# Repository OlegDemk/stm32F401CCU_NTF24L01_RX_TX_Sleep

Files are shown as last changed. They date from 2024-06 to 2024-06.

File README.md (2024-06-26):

The project base on STM32F401CCU microcontroller and NRF24L01 radio module. Project was create on STM32 Cube IDE. 
The RX project: TR all time listen TX modules(up to 6), mark from witch PIPE was(from what TX module data transmeeted), and transmeet reseived data into UART. 

The TX project: Transmeet this data: (32 bytes/one packet)
1. Temperature, Humidity from BME280.
2. Battery voltage. 
3. Retransmitted data packets counter and lost data packets counter. (need for detect lost packets).
After data transmeeting, TX devise go into Stenby mode.
The power consumption(STM32+NRF24l01+BME280) into this mode around 37uA, in condition when device woke up every 5 seconds, and transmeet data every 60 seconds.

Power Consumption
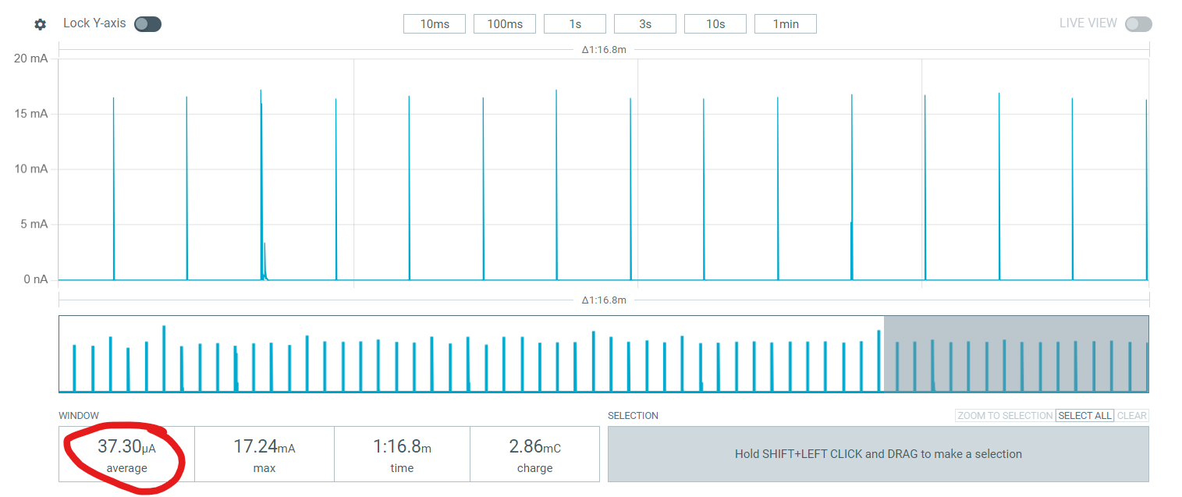
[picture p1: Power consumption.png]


Data:


Settings located on the main.h file
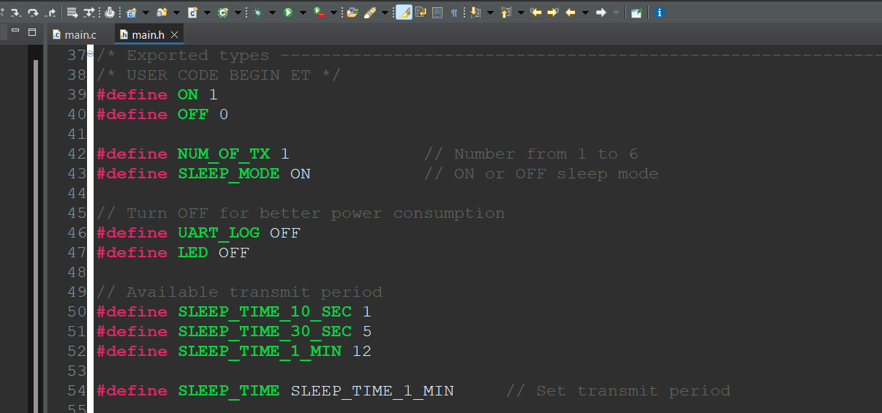
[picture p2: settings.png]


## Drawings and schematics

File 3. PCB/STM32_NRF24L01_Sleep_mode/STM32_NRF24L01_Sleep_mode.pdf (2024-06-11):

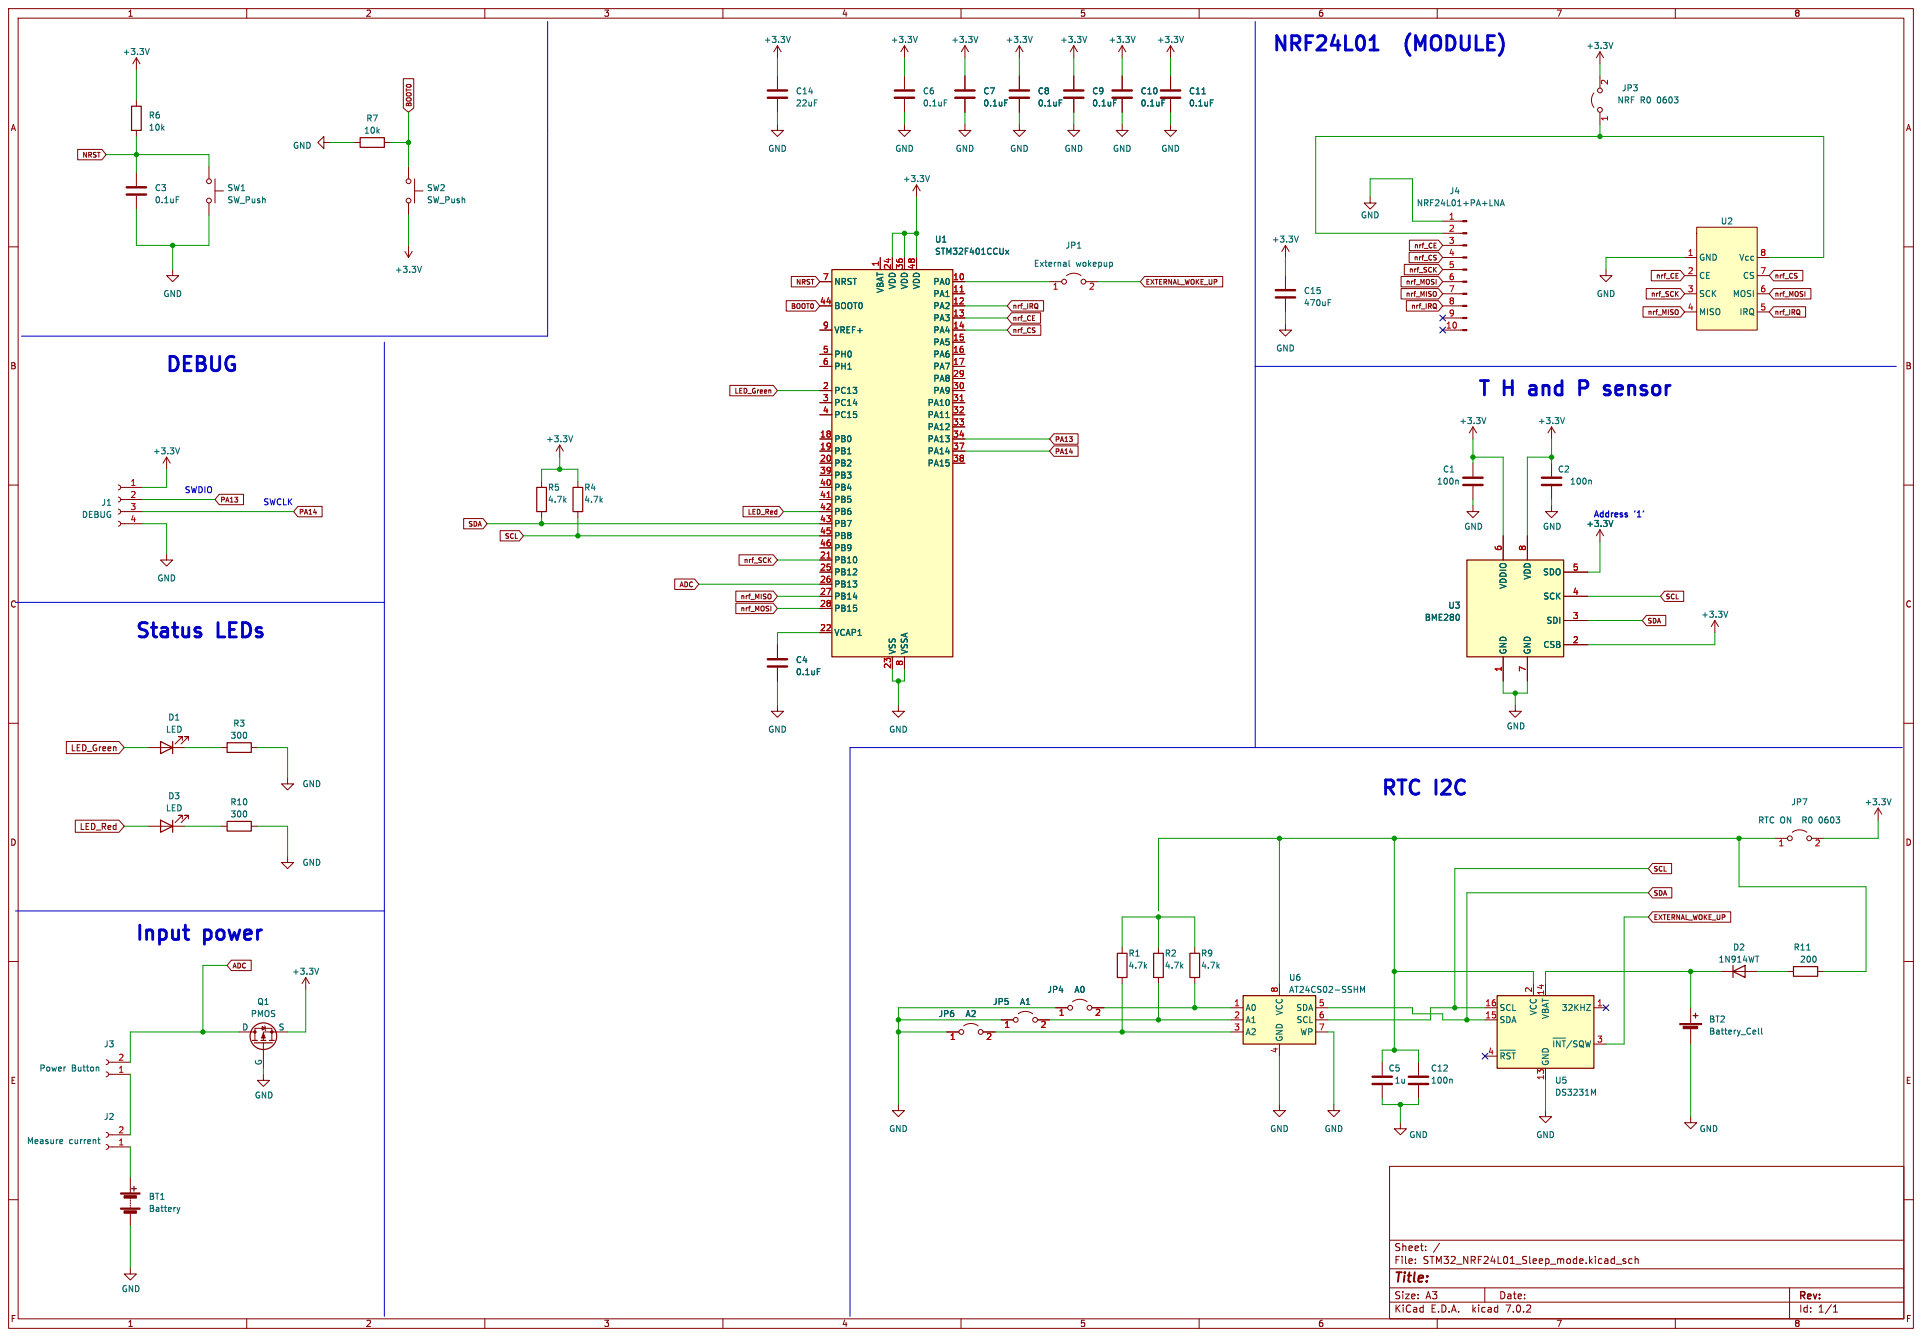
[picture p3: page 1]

nrf_IRQ https://arduino.ua/ru/prod3649-nrf24l01palna-wireless-transceiver-communication-module

1 PA0 10 PA1 11 PA2 12 PA3 13 PA4 14 PA5 15 PA6 16 PA7 17 PB0 18 PB1 19 PC13 2 PB2 20 PB10 21 VCAP1 22 VSS 23 VDD 24 PB12 25 PB13 26 PB14 27 PB15 28 PA8 29 PC14 3 PA9 30 PA10 31 PA11 32 PA12 33 PA13 34 VDD 36 PA14 37 PA15 38 PB3 39 PC15 4 PB4 40 PB5 41 PB6 42 PB7 43 BOOT0 44 PB8 45 PB9 46 VDD 48 PH0 5 PH1 6 NRST 7 VSSA

1 CSB 2 SDI 3 SCK 4 SDO 5 VDDIO

4 SDA 5 SCL 6 WP 7 VCC

Id: 1/1 Title: File: STM32_NRF24L01_Sleep_mode.kicad_sch Sheet: /

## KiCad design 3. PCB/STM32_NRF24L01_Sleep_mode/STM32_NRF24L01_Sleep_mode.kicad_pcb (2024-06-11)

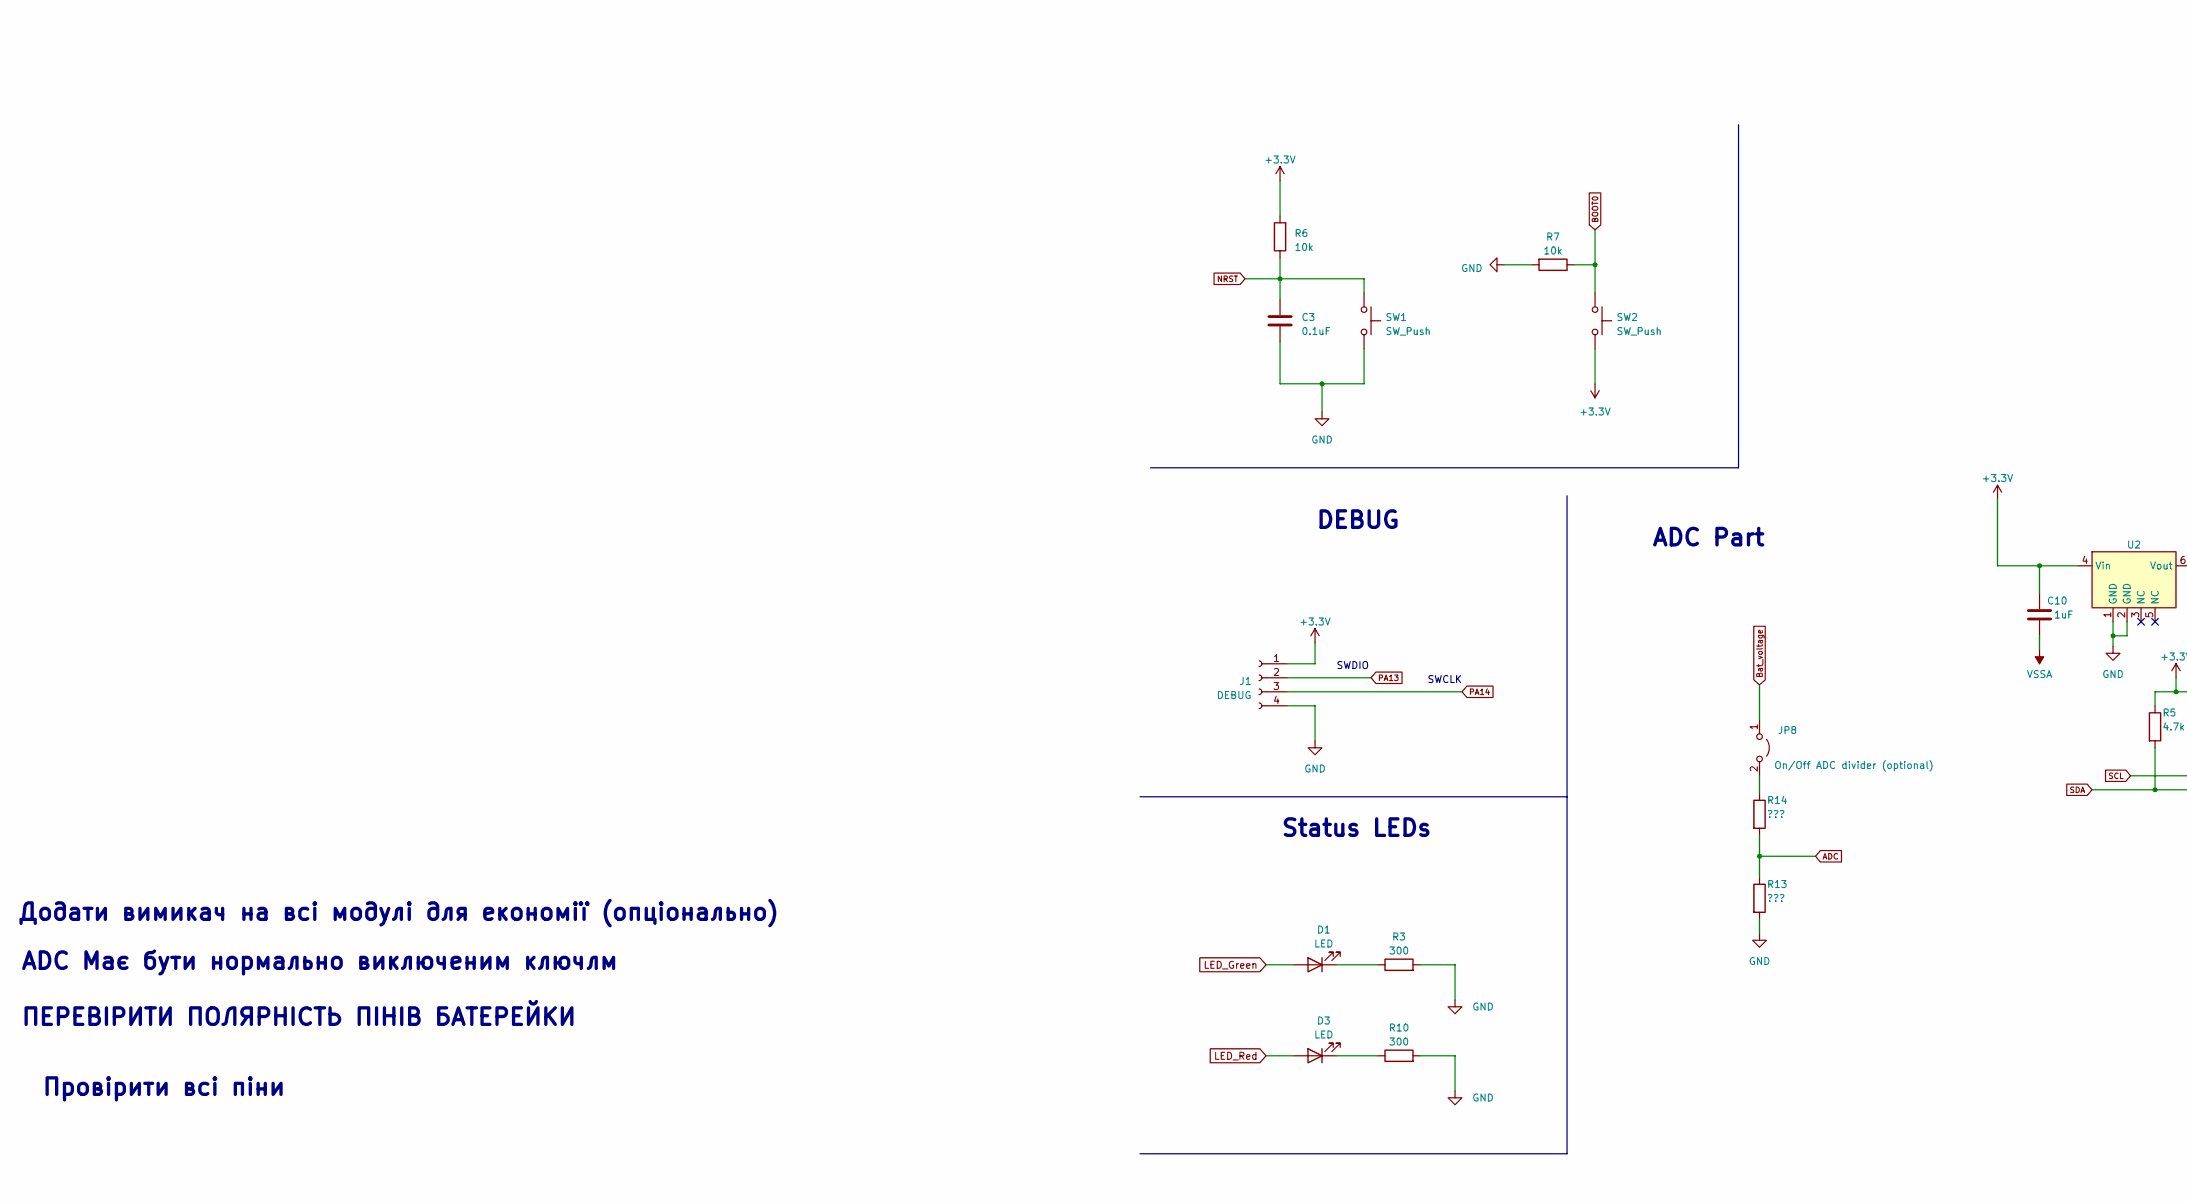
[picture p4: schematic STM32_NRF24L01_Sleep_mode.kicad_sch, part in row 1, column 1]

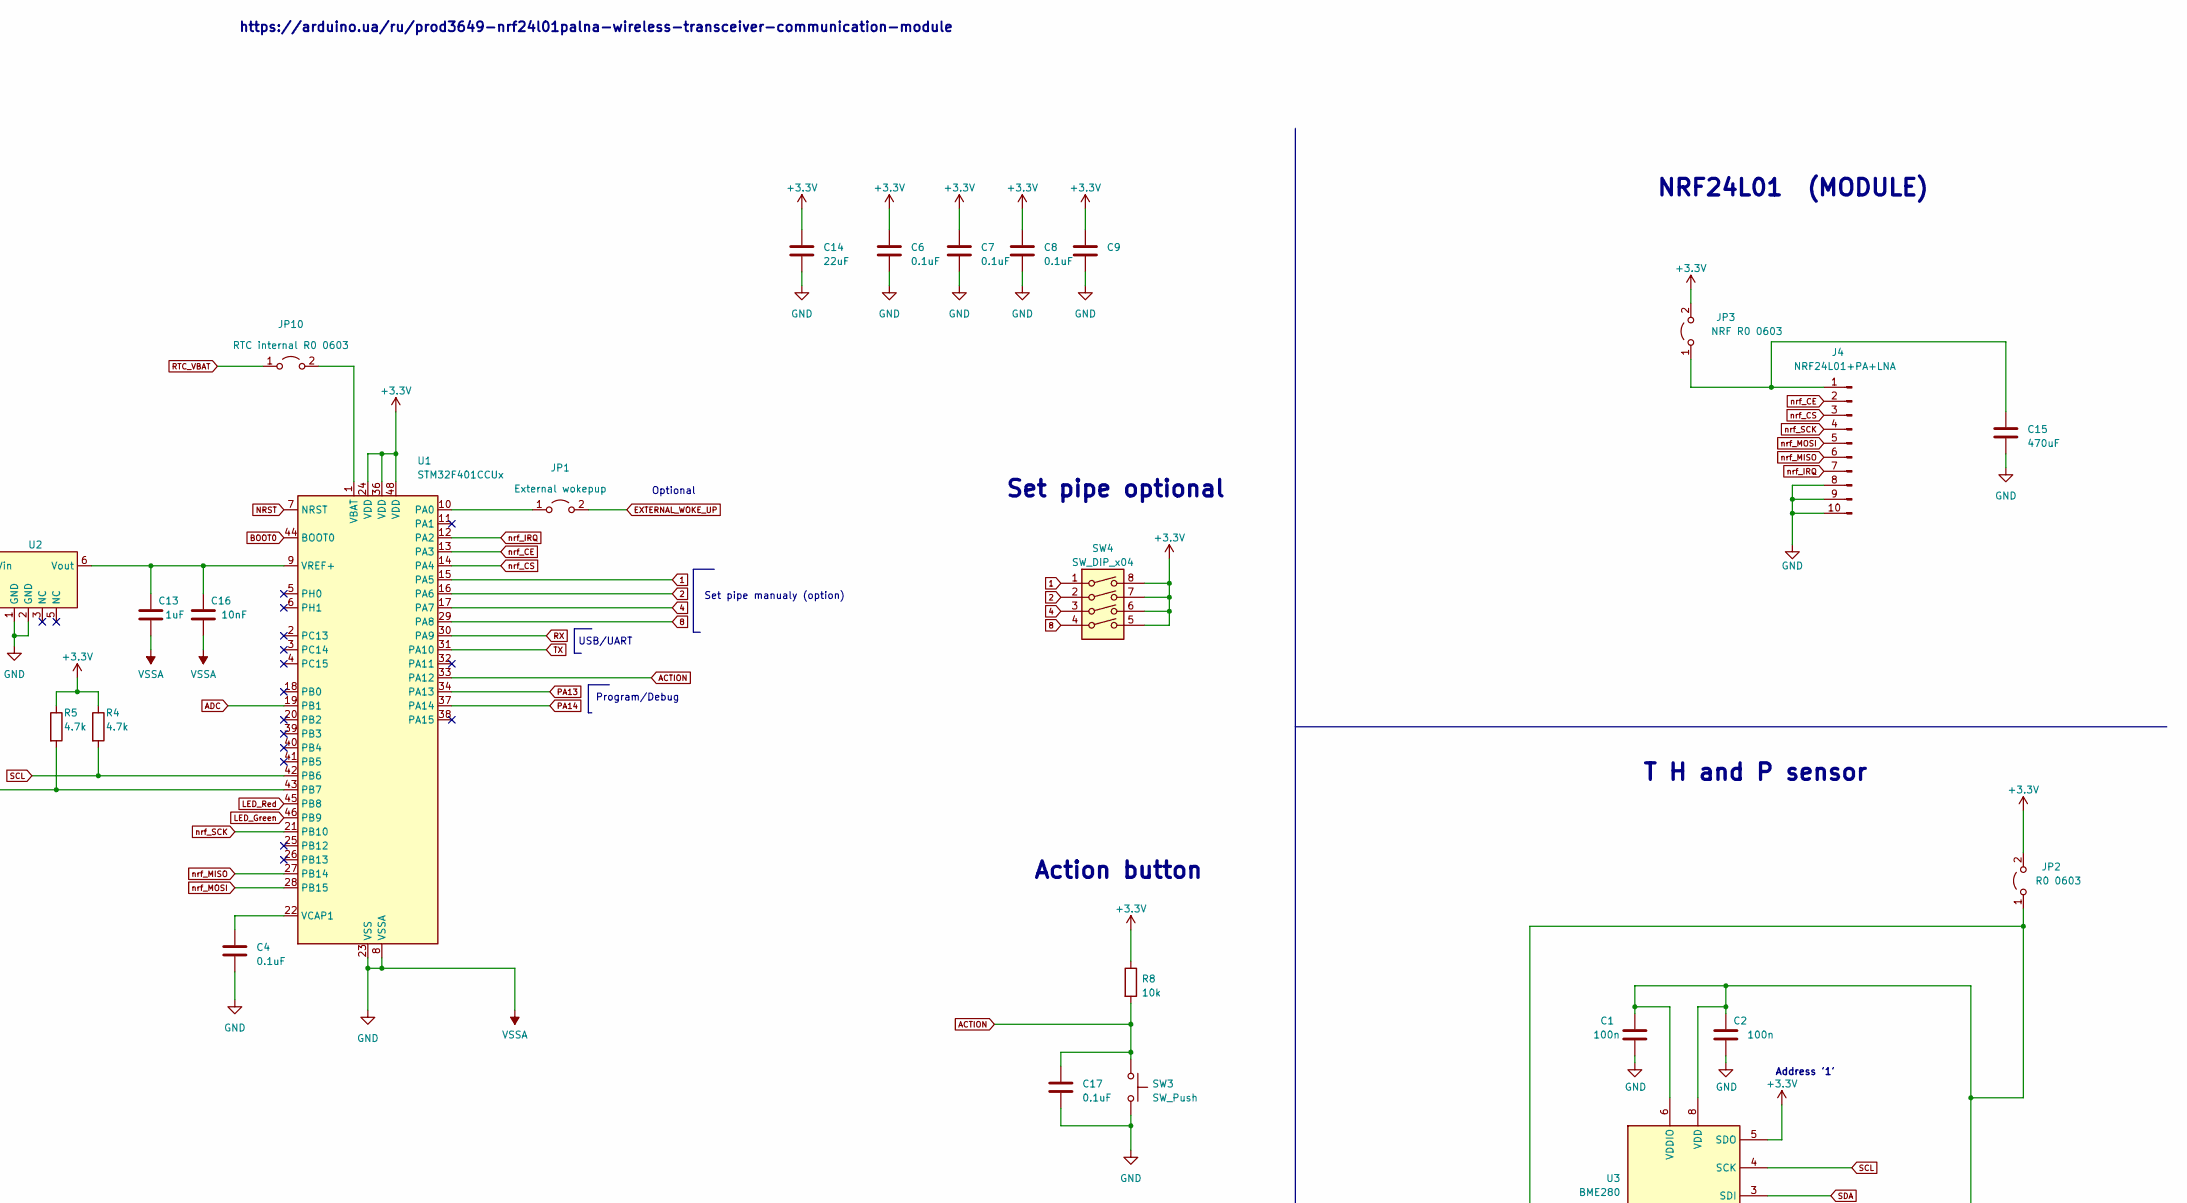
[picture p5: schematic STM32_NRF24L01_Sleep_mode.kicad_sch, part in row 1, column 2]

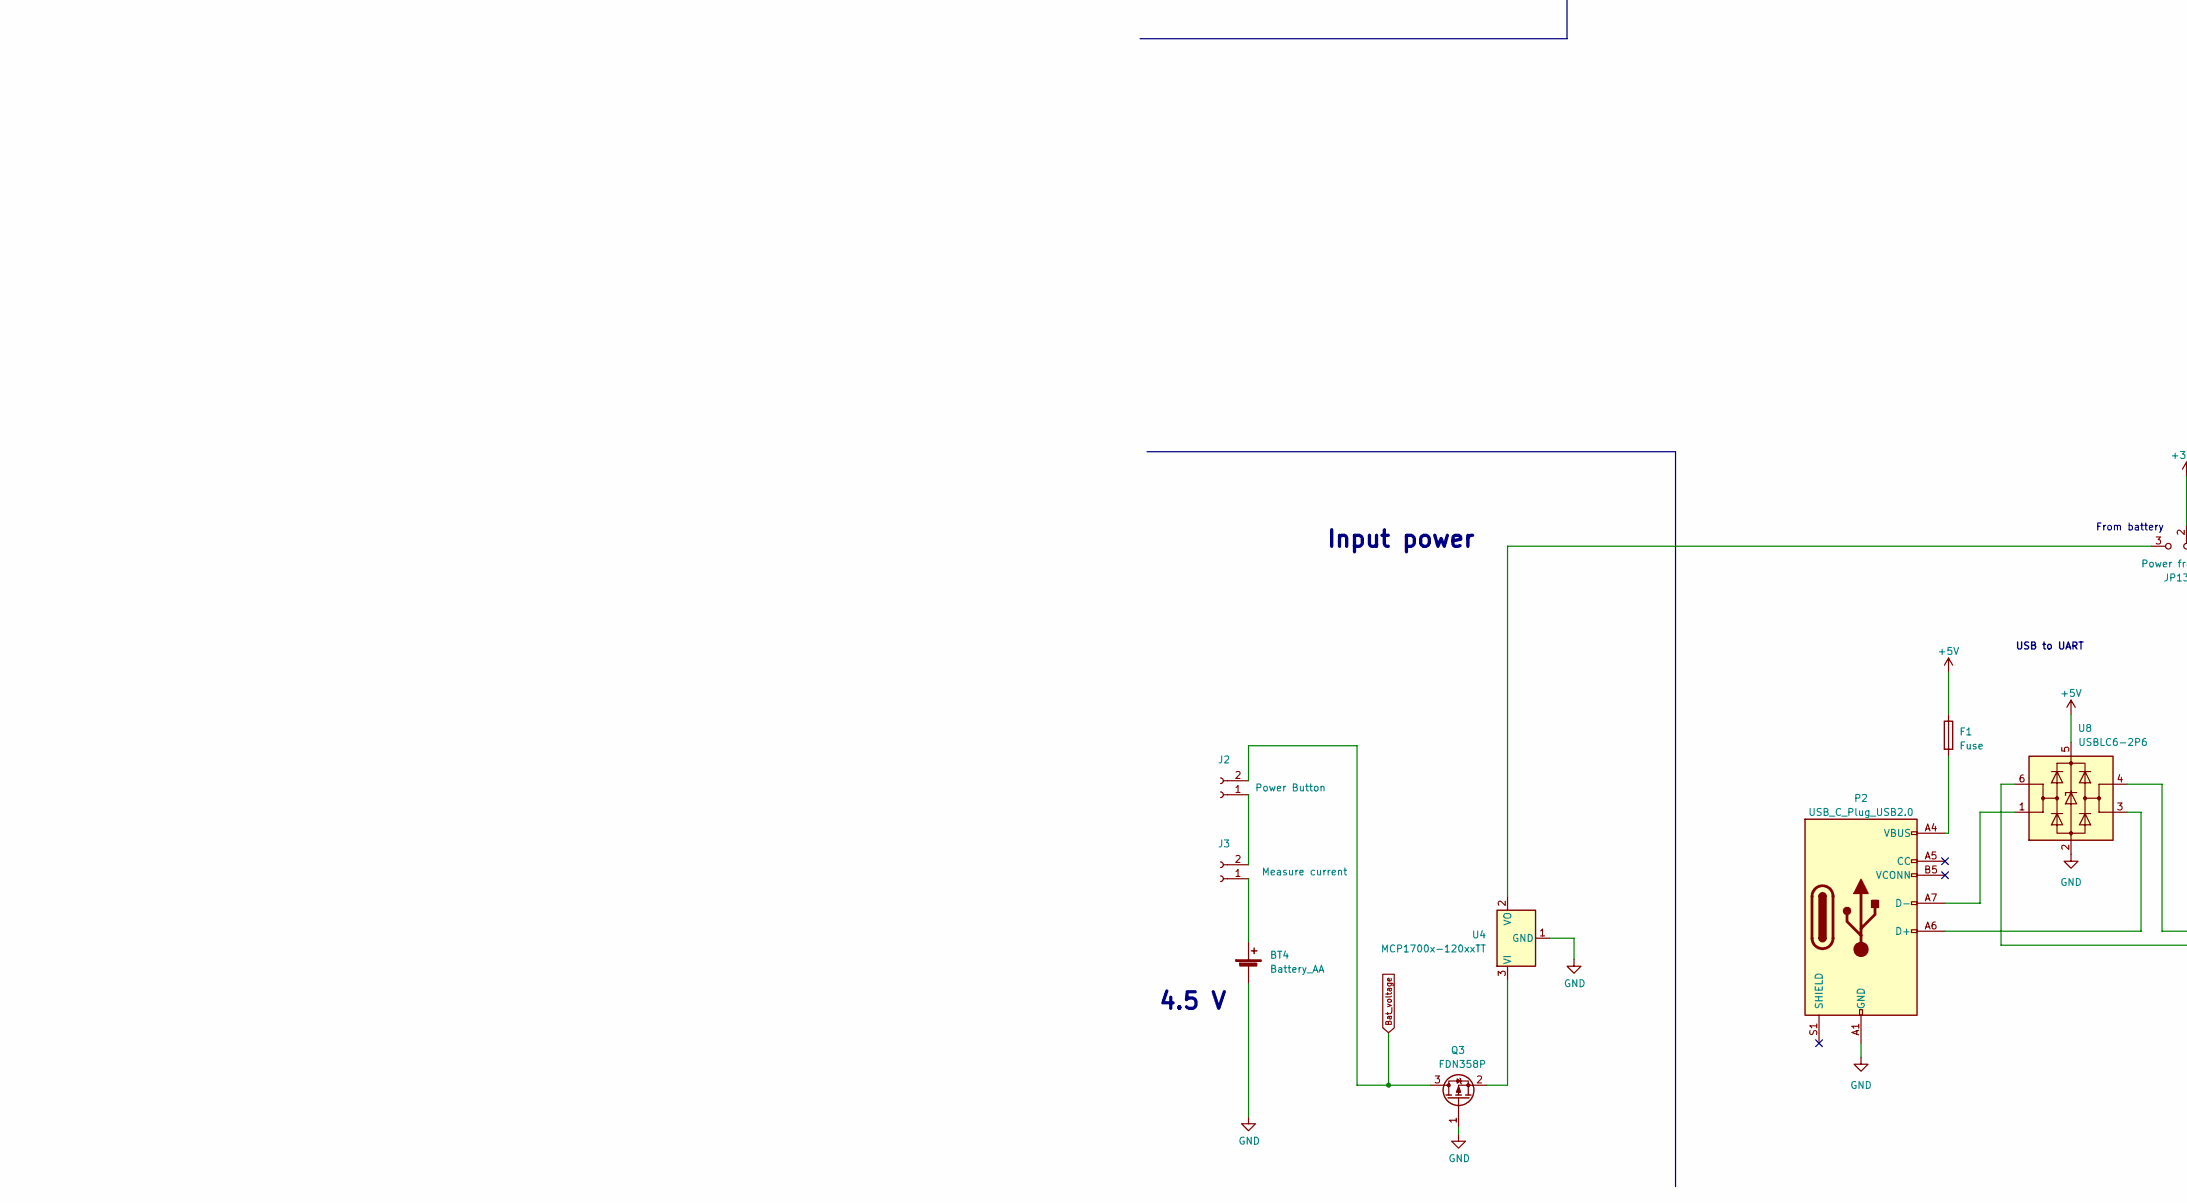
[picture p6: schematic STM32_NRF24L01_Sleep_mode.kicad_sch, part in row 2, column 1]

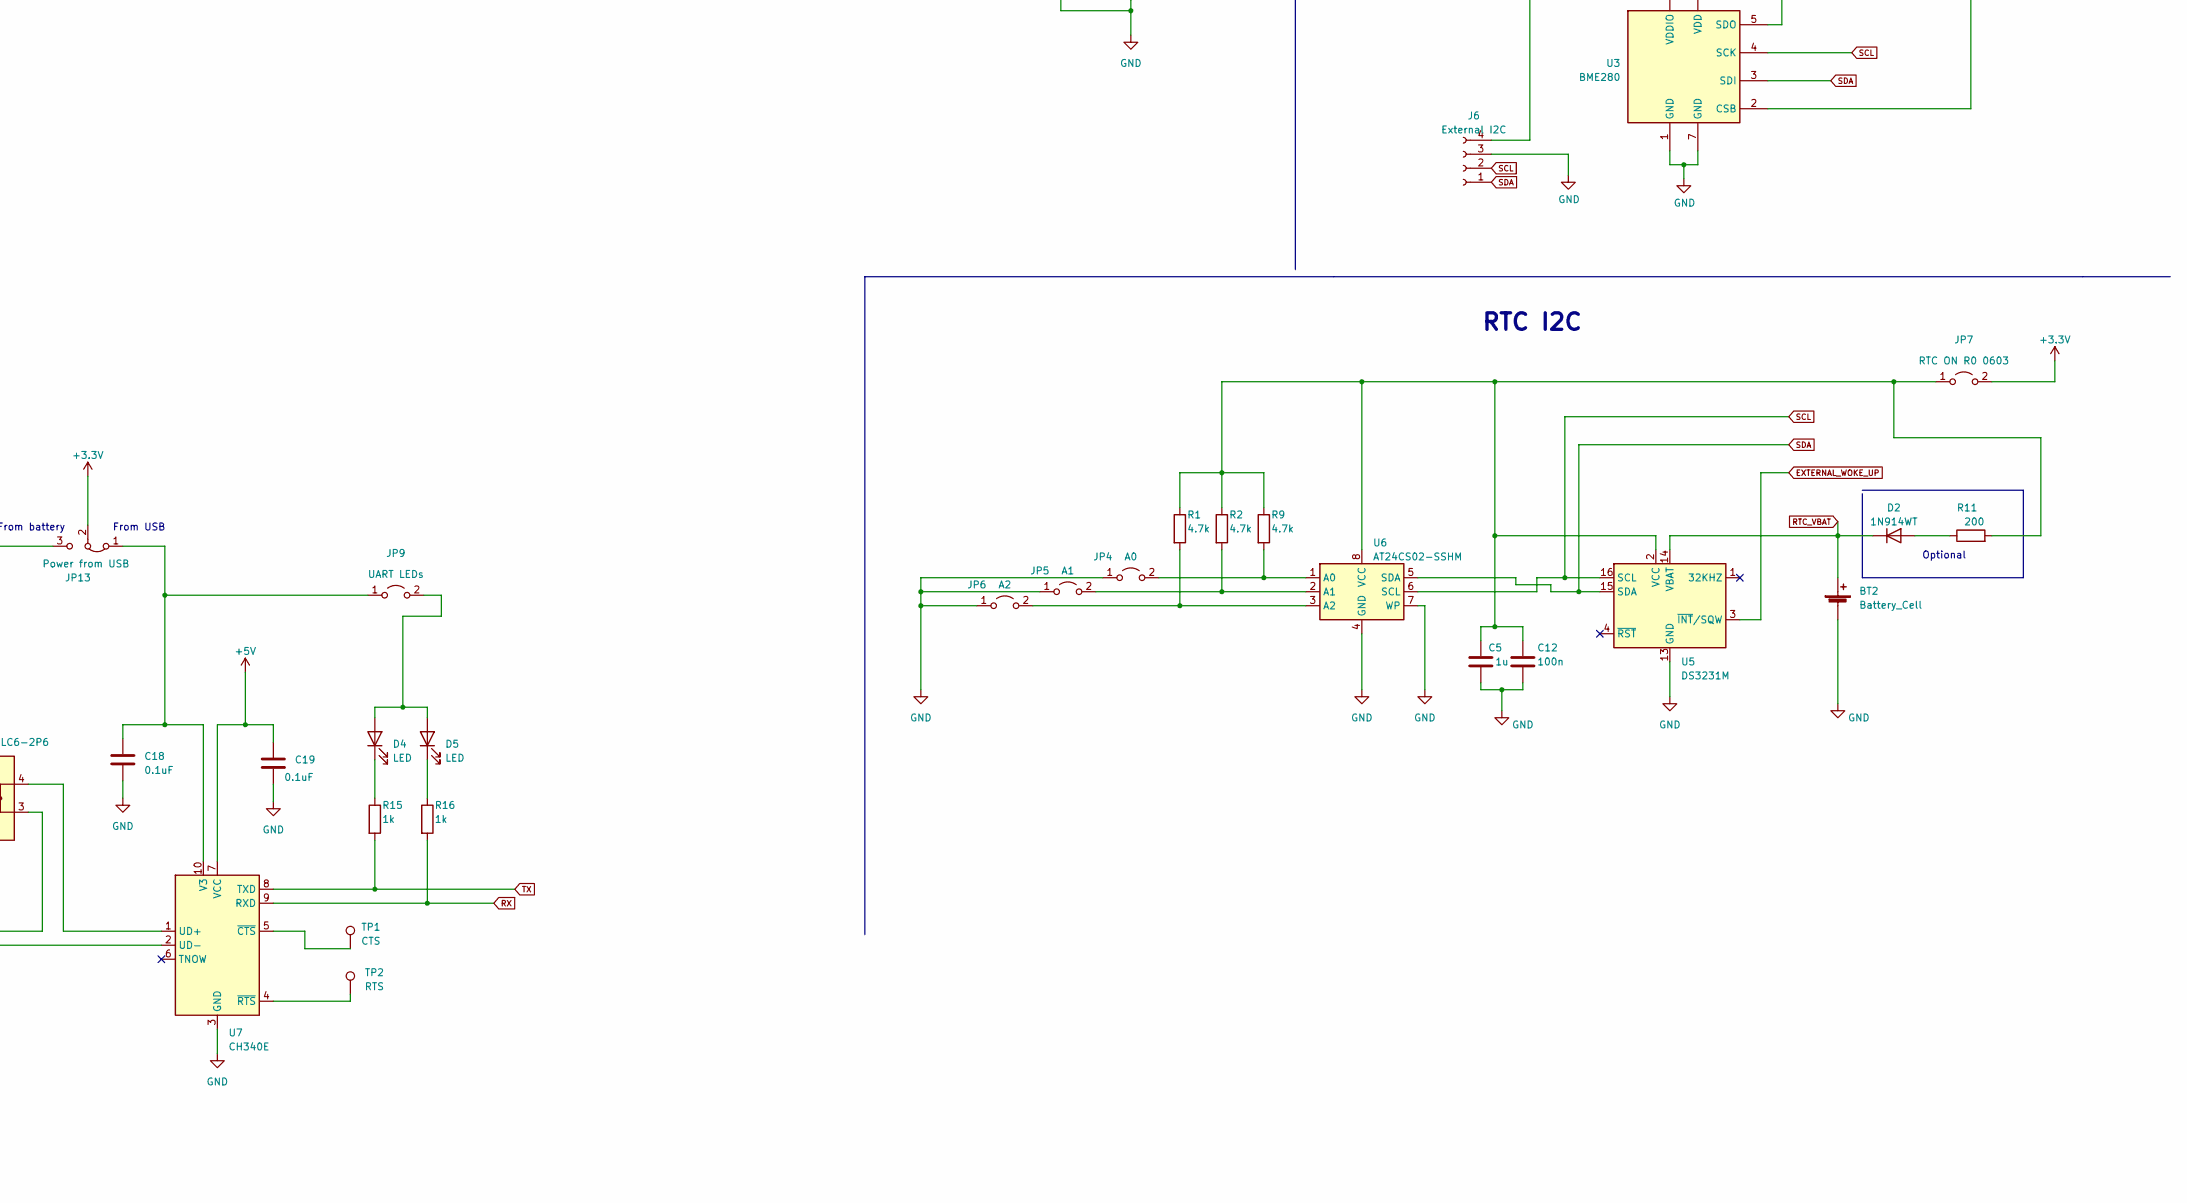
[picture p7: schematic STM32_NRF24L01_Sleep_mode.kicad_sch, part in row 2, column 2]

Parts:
BT2: Battery_Cell; BatteryHolder_MPD_BC2003_1x2032
BT4: Battery_AA; 3X_AA_holder
C1, C2, C12: 100n; C_0603_1608Metric_Pad1.08x0.95mm_HandSolder
C3, C4, C6, C7, C8, C9, C17, C18, C19: 0.1uF; C_0603_1608Metric_Pad1.08x0.95mm_HandSolder
C5: 1u; C_0603_1608Metric_Pad1.08x0.95mm_HandSolder
C10, C13: 1uF; C_0603_1608Metric_Pad1.08x0.95mm_HandSolder
C14: 22uF; R_0805_2012Metric_Pad1.20x1.40mm_HandSolder
C15: 470uF; CP_EIA-7343-31_Kemet-D
C16: 10nF; C_0603_1608Metric_Pad1.08x0.95mm_HandSolder
D1, D3, D4, D5: LED; LED_0402_1005Metric_Pad0.77x0.64mm_HandSolder
D2: 1N914WT; D_MiniMELF
F1: Fuse; Fuse_0603_1608Metric_Pad1.05x0.95mm_HandSolder
J1: DEBUG; PinHeader_1x04_P2.54mm_Vertical_SMD_Pin1Right
J2: Power Button; PinSocket_1x02_P2.54mm_Vertical_SMD_Pin1Left
J3: Measure current; PinSocket_1x02_P2.54mm_Vertical_SMD_Pin1Left
J4: NRF24L01+PA+LNA; NRF24L01
J6: External I2C; PinHeader_1x04_P2.54mm_Vertical_SMD_Pin1Left
JP1: External wokepup; R_0603_1608Metric_Pad0.98x0.95mm_HandSolder
JP2: R0 0603; R_0603_1608Metric_Pad0.98x0.95mm_HandSolder
JP3: NRF R0 0603; R_0603_1608Metric_Pad0.98x0.95mm_HandSolder
JP4: A0; SolderJumper-2_P1.3mm_Open_TrianglePad1.0x1.5mm
JP5: A1; SolderJumper-2_P1.3mm_Open_TrianglePad1.0x1.5mm
JP6: A2; SolderJumper-2_P1.3mm_Open_TrianglePad1.0x1.5mm
JP7: RTC ON R0 0603; R_0603_1608Metric_Pad0.98x0.95mm_HandSolder
JP8: On/Off ADC divider (optional); R_0603_1608Metric_Pad0.98x0.95mm_HandSolder
JP9: UART LEDs; R_0603_1608Metric_Pad0.98x0.95mm_HandSolder
JP10: RTC internal R0 0603; R_0603_1608Metric_Pad0.98x0.95mm_HandSolder
JP13: Power from USB; PinHeader_1x03_P2.54mm_Vertical_SMD_Pin1Right
P2: USB_C_Plug_USB2.0; USB_C_Receptacle_G-Switch_GT-USB-7010ASV
Q3: FDN358P; SOT-23
R1, R2, R4, R5, R9: 4.7k; R_0603_1608Metric_Pad0.98x0.95mm_HandSolder
R3, R10: 300; R_0603_1608Metric_Pad0.98x0.95mm_HandSolder
R6, R7, R8: 10k; R_0603_1608Metric_Pad0.98x0.95mm_HandSolder
R11: 200; R_0603_1608Metric_Pad0.98x0.95mm_HandSolder
R13, R14: ???; R_0603_1608Metric_Pad0.98x0.95mm_HandSolder
R15, R16: 1k; R_0603_1608Metric_Pad0.98x0.95mm_HandSolder
SW1, SW2, SW3: SW_Push; SW_Push_SPST_NO_Alps_SKRK
SW4: SW_DIP_x04; DIP_nuttons_4x
TP1: CTS; TestPoint_Pad_2.0x2.0mm
TP2: RTS; TestPoint_Pad_2.0x2.0mm
U1: STM32F401CCUx; QFN-48-1EP_7x7mm_P0.5mm_EP5.6x5.6mm
U2: SOT-23-6_Handsoldering
U3: BME280; Bosch_LGA-8_2.5x2.5mm_P0.65mm_ClockwisePinNumbering
U4: MCP1700x-120xxTT; SOT-23
U5: DS3231M; SOIC-16W_7.5x10.3mm_P1.27mm
U6: AT24CS02-SSHM; SOIC-8_3.9x4.9mm_P1.27mm
U7: CH340E; MSOP-10_3x3mm_P0.5mm
U8: USBLC6-2P6; SOT-666

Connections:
1: SW4.1, U1.15 (PA5)
2: SW4.2, U1.16 (PA6)
4: SW4.3, U1.17 (PA7)
8: SW4.4, U1.29 (PA8)
+3.3V: C6.1, C7.1, C8.1, C9.1, C10.1, C14.1, J1.1, JP2.2 (B), JP3.2 (B), JP7.2 (B), JP13.2 (C), R4.1, R5.1, R6.2, R8.1, SW2.2, SW4.5, SW4.6, SW4.7, SW4.8, U1.24 (VDD), U1.36 (VDD), U1.48 (VDD), U2.4 (Vin), U3.5 (SDO)
+5V: C19.1, F1.1, U7.7 (VCC), U8.5 (VBUS)
ACTION: C17.1, R8.2, SW3.1, U1.33 (PA12)
ADC: R13.1, R14.2, U1.19 (PB1)
BOOT0: R7.1, SW2.1, U1.44 (BOOT0)
Bat_voltage: J2.2, JP8.1 (A), Q3.3 (D)
EXTERNAL_WOKE_UP: JP1.2 (B), U5.3 (~INT/SQW)
GND: BT2.2 (-), BT4.2 (-), C1.2, C2.2, C3.2, C4.2, C5.2, C6.2, C7.2, C8.2, C9.2, C10.2, C12.2, C13.2, C14.2, C15.2, C16.2, C17.2, C18.2, C19.2, J1.4, J4.8, J4.9, J4.10, J6.3, JP4.1 (A), JP5.1 (A), JP6.1 (A), P2.A1 (GND), P2.A12 (GND), P2.B1 (GND), P2.B12 (GND), Q3.1 (G), R3.2, R7.2, R10.2, R13.2, SW1.2, SW3.2, U1.8 (VSSA), U1.23 (VSS), U1.35 (VSS), U1.47 (VSS), U1.49 (VSS), U2.1 (GND), U2.2 (GND), U3.1 (GND), U3.7 (GND), U4.1 (GND), U5.5 (GND), U5.6 (GND), U5.7 (GND), U5.8 (GND), U5.9 (GND), U5.10 (GND), U5.11 (GND), U5.12 (GND), U5.13 (GND), U6.4 (GND), U6.7 (WP), U7.3 (GND), U8.2 (GND)
LED_Green: D1.2 (A), U1.46 (PB9)
LED_Red: D3.2 (A), U1.45 (PB8)
NRST: C3.1, R6.1, SW1.1, U1.7 (NRST)
unnamed: BT4.1 (+), J3.1
unnamed: D1.1 (K), R3.1
unnamed: D2.2 (A), R11.1
unnamed: D3.1 (K), R10.1
unnamed: D4.2 (A), D5.2 (A), JP9.2 (B)
unnamed: D4.1 (K), R15.1
unnamed: D5.1 (K), R16.1
unnamed: F1.2, P2.A4 (VBUS), P2.A9 (VBUS), P2.B4 (VBUS), P2.B9 (VBUS)
unnamed: J2.1, J3.2
unnamed: C15.1, J4.1, JP3.1 (A)
unnamed: C1.1, C2.1, J6.4, JP2.1 (A), U3.2 (CSB), U3.6 (VDDIO), U3.8 (VDD)
unnamed: JP1.1 (A), U1.10 (PA0)
unnamed: JP4.2 (B), R9.2, U6.1 (A0)
unnamed: JP5.2 (B), R2.2, U6.2 (A1)
unnamed: JP6.2 (B), R1.2, U6.3 (A2)
unnamed: C5.1, C12.1, JP7.1 (A), R1.1, R2.1, R9.1, R11.2, U5.2 (VCC), U6.8 (VCC)
unnamed: JP8.2 (B), R14.1
unnamed: JP10.2 (B), U1.1 (VBAT)
unnamed: C18.1, JP9.1 (A), JP13.1 (A), U7.10 (V3)
unnamed: JP13.3 (B), U4.2 (VO)
unnamed: P2.A6 (D+), U8.3 (I/O2)
unnamed: P2.A7 (D-), U8.1 (I/O1)
unnamed: Q3.2 (S), U4.3 (VI)
unnamed: C4.1, U1.22 (VCAP1)
unnamed: C13.1, C16.1, U1.9 (VREF+), U2.6 (Vout)
unnamed: U7.1 (UD+), U8.4 (I/O2)
unnamed: U7.2 (UD-), U8.6 (I/O1)
unnamed: TP1.1, U7.5 (~CTS)
unnamed: TP2.1, U7.4 (~RTS)
PA13: J1.2, U1.34 (PA13)
PA14: J1.3, U1.37 (PA14)
RTC_VBAT: BT2.1 (+), D2.1 (K), JP10.1 (A), U5.14 (VBAT)
RX: R16.2, U1.30 (PA9), U7.9 (RXD)
SCL: J6.2, R4.2, U1.42 (PB6), U3.4 (SCK), U5.16 (SCL), U6.6 (SCL)
SDA: J6.1, R5.2, U1.43 (PB7), U3.3 (SDI), U5.15 (SDA), U6.5 (SDA)
TX: R15.2, U1.31 (PA10), U7.8 (TXD)
nrf_CE: J4.2, U1.13 (PA3)
nrf_CS: J4.3, U1.14 (PA4)
nrf_IRQ: J4.7, U1.12 (PA2)
nrf_MISO: J4.6, U1.27 (PB14)
nrf_MOSI: J4.5, U1.28 (PB15)
nrf_SCK: J4.4, U1.21 (PB10)

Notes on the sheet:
ПЕРЕВІРИТИ ПОЛЯРНІСТЬ ПІНІВ БАТЕРЕЙКИ
Set pipe manualy (option)
SWDIO
NRF24L01 (MODULE)
4.5 V
T H and P sensor
ADC Part
Status LEDs
Address '1'
ADC Має бути нормально виключеним ключлм
Додати вимикач на всі модулі для економії (опціонально)
USB to UART
https://arduino.ua/ru/prod3649-nrf24l01palna-wireless-transceiver-communication-module
From USB
From battery
Провірити всі піни
USB/UART
Input power
RTC I2C
DEBUG
Program/Debug
Set pipe optional
SWCLK
Optional
Action button

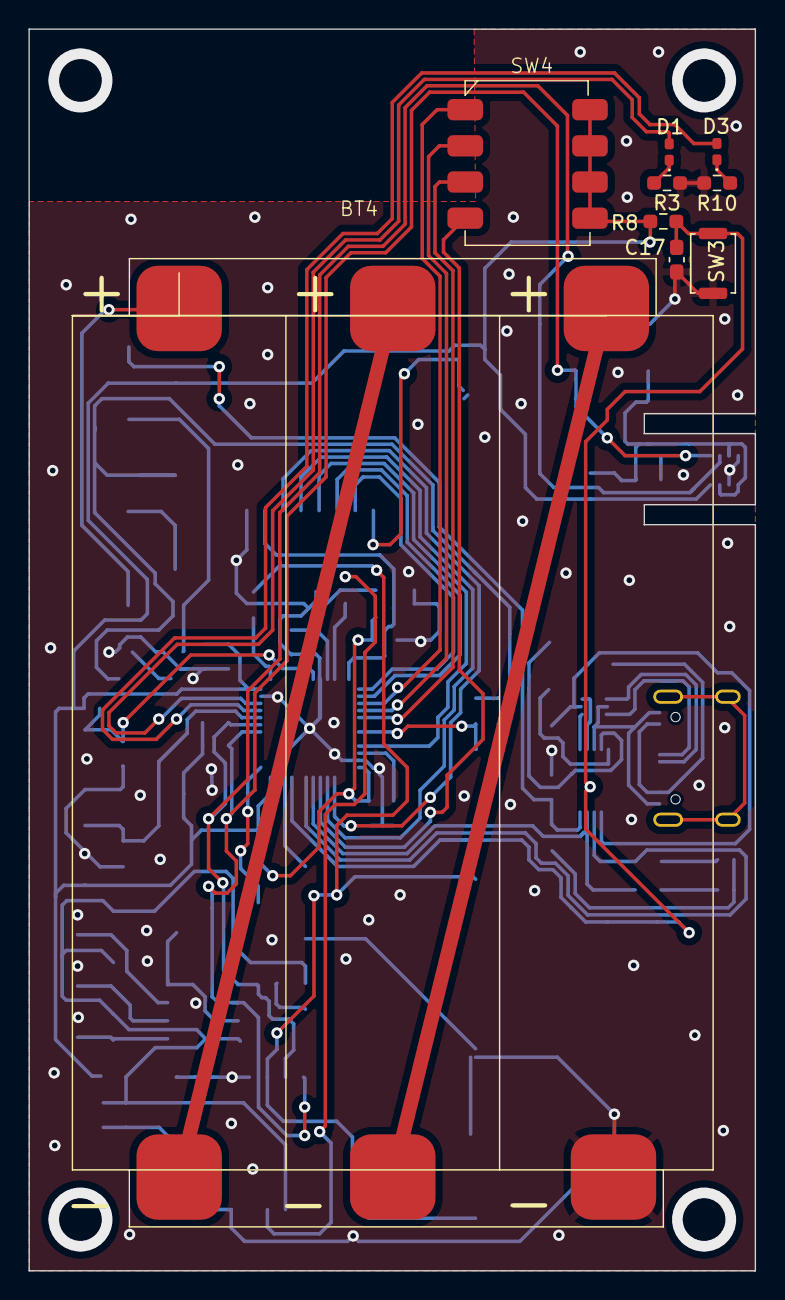
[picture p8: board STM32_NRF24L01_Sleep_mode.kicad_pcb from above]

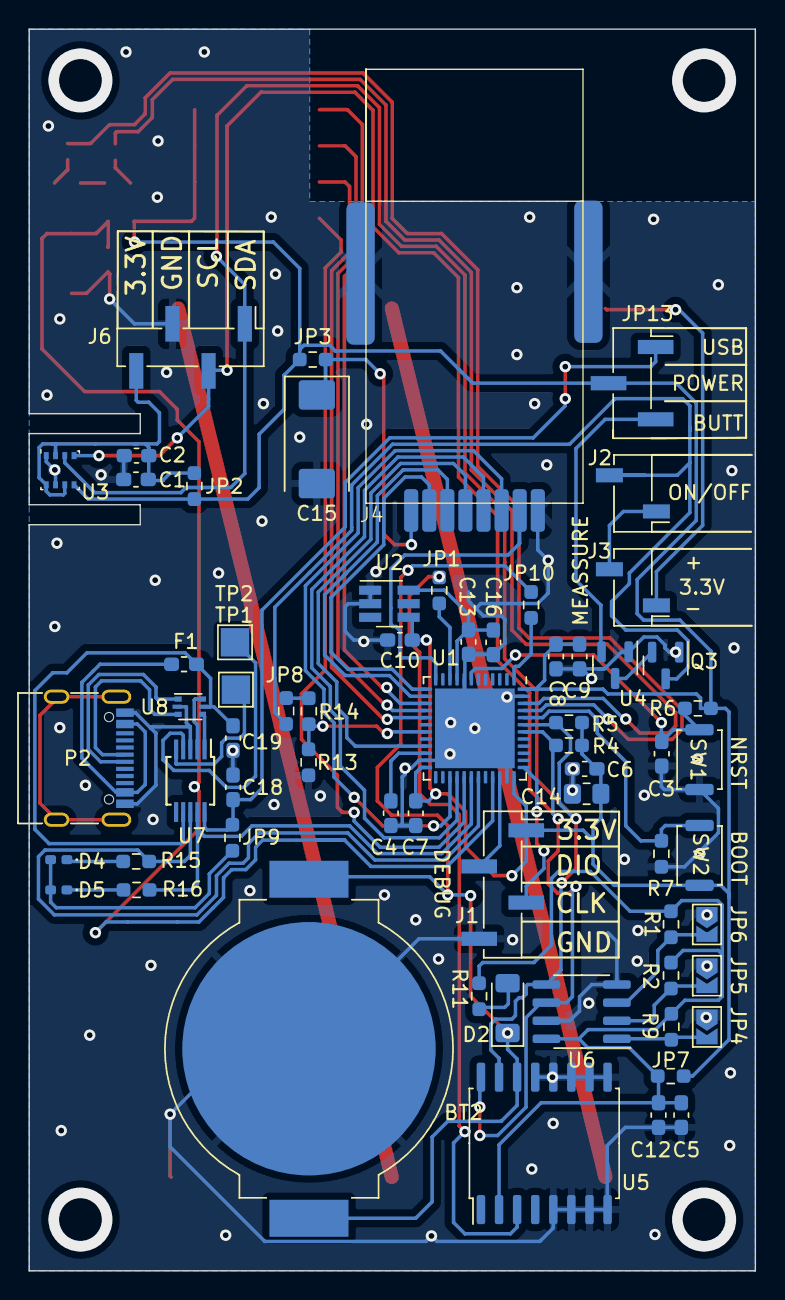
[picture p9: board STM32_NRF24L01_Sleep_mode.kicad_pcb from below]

Board: 2 copper layers, 51.0 x 87.2 mm, 73 parts (64 on the bottom side), 57 nets.

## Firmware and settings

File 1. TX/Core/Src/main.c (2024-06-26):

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
/* Includes ------------------------------------------------------------------*/
#include "main.h"

/* USER CODE BEGIN Includes */
#include "stm32f4xx_hal.h"
#include "stm32f4xx_hal_gpio.h"

#include "BME280/bme280_defs.h"
#include "BME280/bme280.h"
#include "nrf24L01/nrf24L01.h"
#include "DS3231/ds3231.h"
#include "BME280/main_bme280.h"
#include "BATTERY_VOLTAGE/adc_voltage.h"
#include "RTC_DATA/rtc_data_write_read.h"
#include "LEDs/leds.h"
#include "DS3231/main_ds3231.h"
#include "INTERNAL_RTC_TIME/internal_rtc_time.h"


/* USER CODE END Includes */

/* USER CODE BEGIN PD */

// Set wakeUp time
const float  Wake_up_Time_Base = 16.0f/32000.0f;     //0.0005 s
const int WakeUpCounter_1_sec = 1/Wake_up_Time_Base;
const int WakeUpCounter_5_sec = 5/Wake_up_Time_Base;
const int WakeUpCounter_10_sec = 10/Wake_up_Time_Base;


/* USER CODE END PD */

/* USER CODE BEGIN PM */

void send_data(int delay);

/* USER CODE END PM */

ADC_HandleTypeDef hadc1;

I2C_HandleTypeDef hi2c1;

RTC_HandleTypeDef hrtc;

SPI_HandleTypeDef hspi2;

UART_HandleTypeDef huart1;

void SystemClock_Config(void);
static void MX_GPIO_Init(void);
static void MX_RTC_Init(void);
static void MX_I2C1_Init(void);
static void MX_USART1_UART_Init(void);
static void MX_SPI2_Init(void);
static void MX_ADC1_Init(void);
/* USER CODE BEGIN 0 */


// --------------------------------------------------------------------------------------
void settings_mode(void)
{


}
// --------------------------------------------------------------------------------------
void counter(char* buff)
{



}
// --------------------------------------------------------------------------------------
void send_data(int delay)
{
	  // If button was presset more than 5 sec, go to settings mode
	if(HAL_GPIO_ReadPin(GPIOA, ACTION_Pin) == 1)
	{
#if UART_LOG == ON
		char buf_uart_tx[50] = {0,};
		sprintf(buf_uart_tx, "Settings mode\n\r");
		HAL_UART_Transmit(&huart1, buf_uart_tx, sizeof(buf_uart_tx), 1000);
#endif
		led_test_blink(10, 800);
		settings_mode();
	}

	char tramsmeet_data_buffer[70] = {0,};
	char buf_uart_tx[50] = {0,};

#if LED == ON
	GREEN_LED_ON;
#endif
	get_THP_bme280(tramsmeet_data_buffer); 				// Meassure T, H and P
	meassure_battery_voltage(tramsmeet_data_buffer);  	// Meassure voltage on battery
	//read_time_internal_RTC(tramsmeet_data_buffer);

#if UART_LOG == ON
	memset(buf_uart_tx, 0, sizeof(buf_uart_tx));
	sprintf(buf_uart_tx, "TX data: %s \n\r", tramsmeet_data_buffer);
	HAL_UART_Transmit(&huart1, buf_uart_tx, sizeof(buf_uart_tx), 1000);
#endif
	uint8_t dt = 0 ;
	char buf_1[25] = {0,};

	uint32_t RTC_retransmit_packets_cpunter = ReadBackupRegister(RTC_COUNTER_RETRANSMITED_PACKET);
	uint32_t RTC_lost_packets_cpunter = ReadBackupRegister(RTC_COUNTER_LOST_PACKET);
	uint32_t RTC_counter = ReadBackupRegister(RTC_COUNTER_PACKET);

	memset(buf_1, 0, sizeof(buf_1));
	sprintf(buf_1, "C%dR%dL%d", RTC_counter, RTC_retransmit_packets_cpunter, RTC_lost_packets_cpunter);
	strcat(tramsmeet_data_buffer, buf_1);

	NRF24_init_TX(0, 10, 0, 15, 0, 0);
	dt = NRF24L01_Transmit(1, tramsmeet_data_buffer);

	uint8_t retr_packages  = dt & 0xF;			// Select retransmit packets
	uint8_t lost_packages = dt & 0xF0;			// Select lost packets

	// Save data into RTC memory
	WriteBackupRegister(retr_packages, RTC_COUNTER_RETRANSMITED_PACKET);
	WriteBackupRegister(lost_packages, RTC_COUNTER_LOST_PACKET);
	WriteBackupRegister(RTC_counter+1, RTC_COUNTER_PACKET);

#if UART_LOG == ON
	memset(buf_uart_tx, 0, sizeof(buf_uart_tx));
	sprintf(buf_uart_tx, "COUNTER_PACKET: %d, TX retr: %d, TX lost: %d, \n\r", RTC_counter, retr_packages, lost_packages);
	HAL_UART_Transmit(&huart1, buf_uart_tx, sizeof(buf_uart_tx), 1000);
#endif
	if(lost_packages > 0)		// If lost packages was detected
	{
		RED_LED_ON;
		HAL_Delay(10);
		RED_LED_OFF;
	}
	else
	{
		RED_LED_OFF;
	}

#if LED == ON
	GREEN_LED_OFF;
#endif
	NRF24_Sleep_mode();

	HAL_Delay(delay);
}
// --------------------------------------------------------------------------------------
/* USER CODE END 0 */

/**
  * @brief  The application entry point.
  * @retval int
  */
int main(void)
{
  /* MCU Configuration--------------------------------------------------------*/

  /* Reset of all peripherals, Initializes the Flash interface and the Systick. */
  HAL_Init();

  /* Configure the system clock */
  SystemClock_Config();

  /* Initialize all configured peripherals */
  MX_GPIO_Init();
  MX_RTC_Init();
  MX_I2C1_Init();
  MX_USART1_UART_Init();
  MX_SPI2_Init();
  MX_ADC1_Init();
  /* USER CODE BEGIN 2 */


#if SLEEP_MODE == ON
	if (__HAL_PWR_GET_FLAG(PWR_FLAG_SB) != RESET)			// Is device woke up from standby mode ?
	{
		__HAL_PWR_CLEAR_FLAG(PWR_FLAG_SB);  				// clear the flag

		HAL_PWR_DisableWakeUpPin(PWR_WAKEUP_PIN1);  		// disable PA0
		HAL_RTCEx_DeactivateWakeUpTimer(&hrtc);				// Deactivate the RTC wakeup

		// If button was presset more than 5 sec, go to settings mode
		if(HAL_GPIO_ReadPin(GPIOA, ACTION_Pin) == 1)
		{
	#if UART_LOG == ON
			char buf_uart_tx[50] = {0,};
			sprintf(buf_uart_tx, "Settings mode\n\r");
			HAL_UART_Transmit(&huart1, buf_uart_tx, sizeof(buf_uart_tx), 1000);
	#endif

			led_test_blink(10, 800);
			settings_mode();
		}

		  uint32_t period = ReadBackupRegister(RTC_COUNTER_SECOND);

		  if(period >= SLEEP_TIME)		// Wake up time condition
		  {
			  char tramsmeet_data_buffer[70] = {0,};
			  char buf_uart_tx[50] = {0,};

	#if LED == ON
			  GREEN_LED_ON;
	#endif
			  get_THP_bme280(tramsmeet_data_buffer); 				// Meassure T, H and P
			  meassure_battery_voltage(tramsmeet_data_buffer);  	// Meassure voltage on battery
			  //read_time_internal_RTC(tramsmeet_data_buffer);

	#if UART_LOG == ON
			  memset(buf_uart_tx, 0, sizeof(buf_uart_tx));
			  sprintf(buf_uart_tx, "TX data: %s \n\r", tramsmeet_data_buffer);
			  HAL_UART_Transmit(&huart1, buf_uart_tx, sizeof(buf_uart_tx), 1000);
	#endif
			  uint8_t dt = 0 ;
			  char buf_1[25] = {0,};

			  uint32_t RTC_retransmit_packets_cpunter = ReadBackupRegister(RTC_COUNTER_RETRANSMITED_PACKET);
			  uint32_t RTC_lost_packets_cpunter = ReadBackupRegister(RTC_COUNTER_LOST_PACKET);
			  uint32_t RTC_counter = ReadBackupRegister(RTC_COUNTER_PACKET);

			  memset(buf_1, 0, sizeof(buf_1));
			  sprintf(buf_1, "C%dR%dL%d", RTC_counter, RTC_retransmit_packets_cpunter, RTC_lost_packets_cpunter);
			  strcat(tramsmeet_data_buffer, buf_1);

			  NRF24_init_TX(0, 10, 0, 15, 0, 0);
			  dt = NRF24L01_Transmit(1, tramsmeet_data_buffer);

			  uint8_t retr_packages  = dt & 0xF;			// Select retransmit packets
			  uint8_t lost_packages = dt & 0xF0;			// Select lost packets

			  // Save data into RTC memory
			  WriteBackupRegister(retr_packages, RTC_COUNTER_RETRANSMITED_PACKET);
			  WriteBackupRegister(lost_packages, RTC_COUNTER_LOST_PACKET);
			  WriteBackupRegister(RTC_counter+1, RTC_COUNTER_PACKET);

	#if UART_LOG == ON
			  memset(buf_uart_tx, 0, sizeof(buf_uart_tx));
			  sprintf(buf_uart_tx, "COUNTER_PACKET: %d, TX retr: %d, TX lost: %d, \n\r", RTC_counter, retr_packages, lost_packages);
			  HAL_UART_Transmit(&huart1, buf_uart_tx, sizeof(buf_uart_tx), 1000);
	#endif
			  if(lost_packages > 0)		// If lost packages was detected
			  {
				  RED_LED_ON;
				  HAL_Delay(10);
				  RED_LED_OFF;
			  }
			  else
			  {
				  RED_LED_OFF;
			  }

	#if LED == ON
			  GREEN_LED_OFF;
	#endif
			  NRF24_Sleep_mode();

			  WriteBackupRegister(0, RTC_COUNTER_SECOND);
		  }
		  else
		  {
			  WriteBackupRegister(period+1, RTC_COUNTER_SECOND);		// Update counter of seconds
		  }
		  /** Disable the WWAKEUP PIN **/
		  HAL_PWR_DisableWakeUpPin(PWR_WAKEUP_PIN1);  // disable PA0
		  /** Deactivate the RTC wakeup  **/
		  HAL_RTCEx_DeactivateWakeUpTimer(&hrtc);
	   }


	  /** Now enter the standby mode **/
		/* Clear the WU FLAG */
	   __HAL_PWR_CLEAR_FLAG(PWR_FLAG_WU);

		/* clear the RTC Wake UP (WU) flag */
	   __HAL_RTC_WAKEUPTIMER_CLEAR_FLAG(&hrtc, RTC_FLAG_WUTF);


		/* Enable the WAKEUP PIN */
	   HAL_PWR_EnableWakeUpPin(PWR_WAKEUP_PIN1);

	   if (HAL_RTCEx_SetWakeUpTimer_IT(&hrtc, WakeUpCounter_5_sec, RTC_WAKEUPCLOCK_RTCCLK_DIV16) != HAL_OK)
	   {
		 Error_Handler();
	   }

	   /* Finally enter the standby mode */
	   HAL_PWR_EnterSTANDBYMode();

#else





#endif
  /* USER CODE END 2 */

  /* Infinite loop */
  /* USER CODE BEGIN WHILE */
  while (1)
  {
#if SLEEP_MODE == OFF
	  send_data(100);
#endif

    /* USER CODE END WHILE */

    /* USER CODE BEGIN 3 */
  }
  /* USER CODE END 3 */
}

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


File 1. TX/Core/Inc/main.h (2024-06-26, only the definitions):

#define ON 1
#define OFF 0
#define NUM_OF_TX 1				// Number from 1 to 6
#define SLEEP_MODE ON			// ON or OFF sleep mode
#define UART_LOG OFF
#define LED OFF
#define SLEEP_TIME_10_SEC 1
#define SLEEP_TIME_30_SEC 5
#define SLEEP_TIME_1_MIN 12
#define SLEEP_TIME SLEEP_TIME_1_MIN		// Set transmit period
#define RED_LED_ON HAL_GPIO_WritePin(GPIOB, LED_Red_Pin, GPIO_PIN_SET)
#define RED_LED_OFF HAL_GPIO_WritePin(GPIOB, LED_Red_Pin, GPIO_PIN_RESET)
#define RED_LED_TOGLE HAL_GPIO_TogglePin(GPIOB, LED_Red_Pin)
#define GREEN_LED_ON HAL_GPIO_WritePin(GPIOB, LED_Green_Pin, GPIO_PIN_SET)
#define GREEN_LED_OFF HAL_GPIO_WritePin(GPIOB, LED_Green_Pin, GPIO_PIN_RESET)
#define GREEN_LED_TOGLE HAL_GPIO_TogglePin(GPIOB, LED_Green_Pin)
#define nrf_IRQ_Pin GPIO_PIN_2
#define nrf_IRQ_GPIO_Port GPIOA
#define nrf_IRQ_EXTI_IRQn EXTI2_IRQn
#define nrf_CE_Pin GPIO_PIN_3
#define nrf_CE_GPIO_Port GPIOA
#define nrf_CS_Pin GPIO_PIN_4
#define nrf_CS_GPIO_Port GPIOA
#define ACTION_Pin GPIO_PIN_12
#define ACTION_GPIO_Port GPIOA
#define LED_Red_Pin GPIO_PIN_8
#define LED_Red_GPIO_Port GPIOB
#define LED_Green_Pin GPIO_PIN_9
#define LED_Green_GPIO_Port GPIOB

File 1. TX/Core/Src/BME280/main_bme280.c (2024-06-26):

/*
 * main_bme280.c
 *
 *  Created on: Jun 24, 2024
 *      Author: odemki
 */

#include "main.h"
#include "stm32f4xx_hal.h"
#include <string.h>
#include <stdio.h>

#include "BME280/main_bme280.h"
#include "BME280/bme280.h"
#include "BME280/bme280_defs.h"



extern I2C_HandleTypeDef hi2c1;

struct bme280_dev dev;
struct bme280_data comp_data;
//	int8_t rslt;



//----------------------------------------------------------------------------------------
int8_t user_i2c_read(uint8_t id, uint8_t reg_addr, uint8_t *data, uint16_t len)
{
	if(HAL_I2C_Master_Transmit(&hi2c1, (id << 1), &reg_addr, 1, 10) != HAL_OK) return -1;
	if(HAL_I2C_Master_Receive(&hi2c1, (id << 1) | 0x01, data, len, 10) != HAL_OK) return -1;

	return 0;
}
//----------------------------------------------------------------------------------------
void user_delay_ms(uint32_t period)
{
	HAL_Delay(period);
}
//----------------------------------------------------------------------------------------
int8_t user_i2c_write(uint8_t id, uint8_t reg_addr, uint8_t *data, uint16_t len)
{
	int8_t *buf;
	buf = malloc(len +1);
	buf[0] = reg_addr;
	memcpy(buf +1, data, len);

	if(HAL_I2C_Master_Transmit(&hi2c1, (id << 1), (uint8_t*)buf, len + 1, HAL_MAX_DELAY) != HAL_OK) return -1;

	free(buf);
	return 0;
}
//----------------------------------------------------------------------------------------
void init_bme280_(void)
{
	uint16_t STATUS=0;
	uint16_t addres_device = 0x76;  		 		// BME280
	uint16_t id_addr = 0xD0;
	uint8_t id = 96;								// in hex form
	uint8_t buff=0;        						// Return 0x96 -> Dec 60
	int8_t rslt;

	// For debug
	STATUS = HAL_I2C_Mem_Read(&hi2c1, addres_device<<1, id_addr, 1, &buff, 1, 1000);
	if(!((buff == id) && (STATUS == 0)))
	{
		error_blink_red_led();
	}

	// Init BME280
	dev.dev_id = BME280_I2C_ADDR_PRIM;
	dev.intf = BME280_I2C_INTF;
	dev.read = user_i2c_read;
	dev.write = user_i2c_write;
	dev.delay_ms = user_delay_ms;

	rslt = bme280_init(&dev);

	dev.settings.osr_h = BME280_OVERSAMPLING_1X;
	dev.settings.osr_p = BME280_OVERSAMPLING_16X;
	dev.settings.osr_t = BME280_OVERSAMPLING_2X;
	dev.settings.filter = BME280_FILTER_COEFF_16;
	rslt = bme280_set_sensor_settings(BME280_OSR_PRESS_SEL | BME280_OSR_TEMP_SEL | BME280_OSR_HUM_SEL | BME280_FILTER_SEL, &dev);
	rslt = bme280_set_sensor_mode(BME280_NORMAL_MODE, &dev);

	dev.delay_ms(40);
}
//----------------------------------------------------------------------------------------
void get_THP_bme280(char * buff)
{
	init_bme280_();

	float BME280_temperature = 0;
	float BME280_humidity = 0;
	float BME280_preasure = 0;

	if(bme280_get_sensor_data(BME280_ALL, &comp_data, &dev) == BME280_OK)
	{
		// Save data variables
		BME280_temperature = (float)comp_data.temperature;
		BME280_humidity = (float)comp_data.humidity;
		BME280_preasure = (float)comp_data.pressure;
	}
	else
	{
		error_blink_red_led();
	}

	if(put_device_to_sleep(&dev) != 0)
	{
		error_blink_red_led();
	}


	char buffer[10] = {0,};

	memset(buffer, 0, sizeof(buffer));
	sprintf(buffer, "T%.1f", BME280_temperature);
	strcat(buff, buffer);

	memset(buffer, 0, sizeof(buffer));
	sprintf(buffer, "H%.1f", BME280_humidity);
	strcat(buff, buffer);

}

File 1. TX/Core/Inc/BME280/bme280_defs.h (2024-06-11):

/*
 * bme280_defs.h
 *
 *  Created on: May 13, 2024
 *      Author: odemki
 */

#ifndef INC_BME280_BME280_DEFS_H_
#define INC_BME280_BME280_DEFS_H_

/********************************************************/
/* header includes */
#ifdef __KERNEL__
#include <linux/types.h>
#include <linux/kernel.h>
#else
#include <stdint.h>
#include <stddef.h>
#endif

/********************************************************/
/*! @name		Common macros		        */
/********************************************************/

#if !defined(UINT8_C) && !defined(INT8_C)
#define INT8_C(x)       S8_C(x)
#define UINT8_C(x)      U8_C(x)
#endif

#if !defined(UINT16_C) && !defined(INT16_C)
#define INT16_C(x)      S16_C(x)
#define UINT16_C(x)     U16_C(x)
#endif

#if !defined(INT32_C) && !defined(UINT32_C)
#define INT32_C(x)      S32_C(x)
#define UINT32_C(x)     U32_C(x)
#endif

#if !defined(INT64_C) && !defined(UINT64_C)
#define INT64_C(x)      S64_C(x)
#define UINT64_C(x)     U64_C(x)
#endif

/**@}*/

/**\name C standard macros */
#ifndef NULL
#ifdef __cplusplus
#define NULL   0
#else
#define NULL   ((void *) 0)
#endif
#endif
/********************************************************/

#ifndef BME280_FLOAT_ENABLE
#define BME280_FLOAT_ENABLE
#endif

#ifndef BME280_FLOAT_ENABLE
#ifndef BME280_64BIT_ENABLE
// #define BME280_64BIT_ENABLE  // EPV
#endif
#endif

#ifndef TRUE
#define TRUE                UINT8_C(1)
#endif
#ifndef FALSE
#define FALSE               UINT8_C(0)
#endif

/**\name I2C addresses */
#define BME280_I2C_ADDR_PRIM	UINT8_C(0x76)
#define BME280_I2C_ADDR_SEC		UINT8_C(0x77)

/**\name BME280 chip identifier */
#define BME280_CHIP_ID  UINT8_C(0x60)

/**\name Register Address */
#define BME280_CHIP_ID_ADDR					UINT8_C(0xD0)
#define BME280_RESET_ADDR					UINT8_C(0xE0)
#define BME280_TEMP_PRESS_CALIB_DATA_ADDR	UINT8_C(0x88)
#define BME280_HUMIDITY_CALIB_DATA_ADDR		UINT8_C(0xE1)
#define BME280_PWR_CTRL_ADDR				UINT8_C(0xF4)
#define BME280_CTRL_HUM_ADDR				UINT8_C(0xF2)
#define BME280_CTRL_MEAS_ADDR				UINT8_C(0xF4)
#define BME280_CONFIG_ADDR					UINT8_C(0xF5)
#define BME280_DATA_ADDR					UINT8_C(0xF7)

/**\name API success code */
#define BME280_OK					INT8_C(0)

/**\name API error codes */
#define BME280_E_NULL_PTR			INT8_C(-1)
#define BME280_E_DEV_NOT_FOUND		INT8_C(-2)
#define BME280_E_INVALID_LEN		INT8_C(-3)
#define BME280_E_COMM_FAIL			INT8_C(-4)
#define BME280_E_SLEEP_MODE_FAIL	INT8_C(-5)

/**\name API warning codes */
#define BME280_W_INVALID_OSR_MACRO      INT8_C(1)

/**\name Macros related to size */
#define BME280_TEMP_PRESS_CALIB_DATA_LEN	UINT8_C(26)
#define BME280_HUMIDITY_CALIB_DATA_LEN		UINT8_C(7)
#define BME280_P_T_H_DATA_LEN				UINT8_C(8)

/**\name Sensor power modes */
#define	BME280_SLEEP_MODE		UINT8_C(0x00)
#define	BME280_FORCED_MODE		UINT8_C(0x01)
#define	BME280_NORMAL_MODE		UINT8_C(0x03)

/**\name Macro to combine two 8 bit data's to form a 16 bit data */
#define BME280_CONCAT_BYTES(msb, lsb)     (((uint16_t)msb << 8) | (uint16_t)lsb)

#define BME280_SET_BITS(reg_data, bitname, data) \
				((reg_data & ~(bitname##_MSK)) | \
				((data << bitname##_POS) & bitname##_MSK))
#define BME280_SET_BITS_POS_0(reg_data, bitname, data) \
				((reg_data & ~(bitname##_MSK)) | \
				(data & bitname##_MSK))

#define BME280_GET_BITS(reg_data, bitname)  ((reg_data & (bitname##_MSK)) >> \
							(bitname##_POS))
#define BME280_GET_BITS_POS_0(reg_data, bitname)  (reg_data & (bitname##_MSK))

/**\name Macros for bit masking */
#define BME280_SENSOR_MODE_MSK	UINT8_C(0x03)
#define BME280_SENSOR_MODE_POS	UINT8_C(0x00)

#define BME280_CTRL_HUM_MSK		UINT8_C(0x07)
#define BME280_CTRL_HUM_POS		UINT8_C(0x00)

#define BME280_CTRL_PRESS_MSK	UINT8_C(0x1C)
#define BME280_CTRL_PRESS_POS	UINT8_C(0x02)

#define BME280_CTRL_TEMP_MSK	UINT8_C(0xE0)
#define BME280_CTRL_TEMP_POS	UINT8_C(0x05)

#define BME280_FILTER_MSK		UINT8_C(0x1C)
#define BME280_FILTER_POS		UINT8_C(0x02)

#define BME280_STANDBY_MSK		UINT8_C(0xE0)
#define BME280_STANDBY_POS		UINT8_C(0x05)

/**\name Sensor component selection macros
   These values are internal for API implementation. Don't relate this to
   data sheet.*/
#define BME280_PRESS		UINT8_C(1)
#define BME280_TEMP			UINT8_C(1 << 1)
#define BME280_HUM			UINT8_C(1 << 2)
#define BME280_ALL			UINT8_C(0x07)

/**\name Settings selection macros */
#define BME280_OSR_PRESS_SEL		UINT8_C(1)
#define BME280_OSR_TEMP_SEL			UINT8_C(1 << 1)
#define BME280_OSR_HUM_SEL			UINT8_C(1 << 2)
#define BME280_FILTER_SEL			UINT8_C(1 << 3)
#define BME280_STANDBY_SEL			UINT8_C(1 << 4)
#define BME280_ALL_SETTINGS_SEL		UINT8_C(0x1F)

/**\name Oversampling macros */
#define BME280_NO_OVERSAMPLING		UINT8_C(0x00)
#define BME280_OVERSAMPLING_1X		UINT8_C(0x01)
#define BME280_OVERSAMPLING_2X		UINT8_C(0x02)
#define BME280_OVERSAMPLING_4X		UINT8_C(0x03)
#define BME280_OVERSAMPLING_8X		UINT8_C(0x04)
#define BME280_OVERSAMPLING_16X		UINT8_C(0x05)
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

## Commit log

2024-06-11 Two TX devices was added
2024-06-12 Refactoring code
    [STM32_NRF24L01_Sleep_mode.kicad_sch]
2024-06-13 TX on sleep mode, 0,240 mA with external RTC, Transmit data every 20 sec
    [sleep_project.kicad_pcb, sleep_project.kicad_sch]
2024-06-13 Microcontroller friquenses was decrease from 64 MHz to 8 MHz. Power consumption is 0.210 mA
2024-06-17 Update TX dev, use internal RTC, power cunsumption 50 uA
2024-06-26 Tx and Rx only, power consumption 40uA
    [sleep_project.kicad_pcb, sleep_project.kicad_sch]
2024-06-26 power consumprion measure was added

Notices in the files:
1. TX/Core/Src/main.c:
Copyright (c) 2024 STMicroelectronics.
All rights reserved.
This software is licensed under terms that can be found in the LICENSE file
